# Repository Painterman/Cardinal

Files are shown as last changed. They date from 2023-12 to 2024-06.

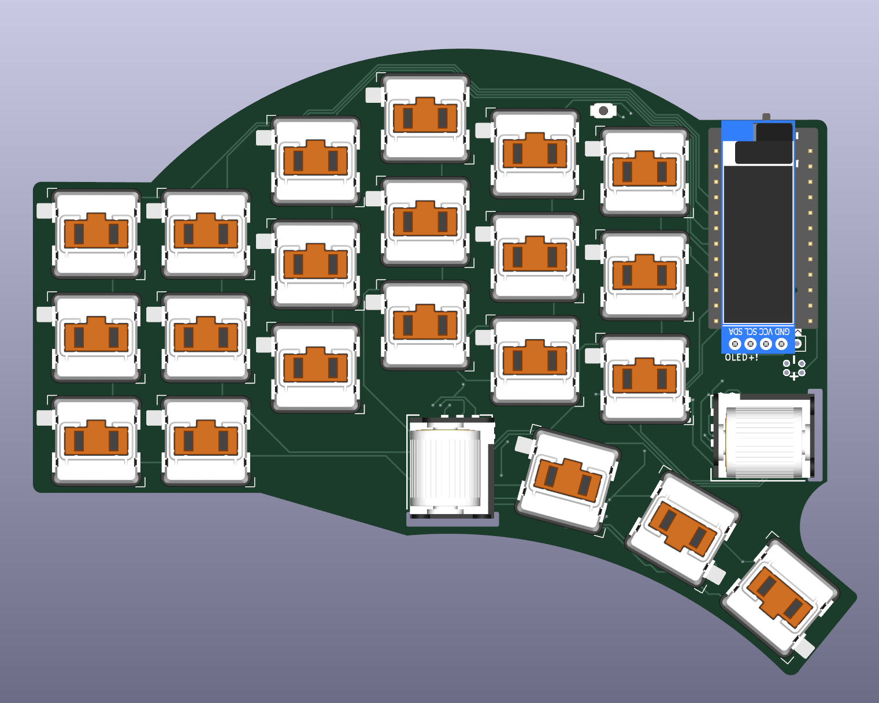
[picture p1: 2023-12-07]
Pictures/PCB-Front.png

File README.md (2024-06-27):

# Cardinal
The keyboard
 Introducing: Cardinal, a split, fully wireless, low profile with choc spacing and hotswap sockets with optional encoders, screens and 5 position switches.

 As this update this should be in a working state and mostly finished, you can find the Kicad project Gerbers ready to order, and the case files in /Case
 
# Why?

For a while now I have been using a ferris sweep on and off and wanted to go back to more keys and features. 
Looking at other keyboard projects i found about the Panasonic EVQWGD encoders and the 5 position switches like SKRHA line from alps and wanted to make a keyboard with both of these, options for displays and other features that I might like.

Fast-forward and here we are, my first keyboard design taking clues from multiple other community designs.

# Features

    -Fully wireless, designed around Nice!Nano or other controllers with the same pinout/wireless capability due to the lack of trss jack.
    -Reversible pcb.
    -2 encoders support per side, or 1 encoder and 1 5 position switch.
    -Choc spacing and hotswap sockets.
    -Oled display or Nice!View support.

 Things i might end up doing:
 
    - More versions: support for different encoders and for less keys.
    - Maybe a reduced choc spacing board.
    - Non hotswap version.
    - investigate into wireless charging

# BOM

Use this as a reference, you can find a more detailed build guide on the wiki.

| Part | Quantity | Notes| 
| :--- | :---: | :--- |
| PCB | 2 | Use your preferred pcb manufacturing service, mine came from pcbgogo (not affiliated), the size of the pcbs is 135x100, so its a bit more expensive than the sub 100x100 |
| Pro Micro footprint microcontroller | 2 | Designed with Nice!Nano Bluetooth in mind, I’m using ProMicro NRF52840 |
| Choc key switches | 42 or less | You have the option to breakaway the extra pinkie column, or even just use less thumb keys |
| Choc hotswap sockets | Same as switches | 1 per key|
| 1N4148WS SOD123 diodes  | 48 or less | 1 per key, 2 per half for encoders and 2 for 5 way switch | 
| EVQWGD001 rotary encoders | 4 or less | I’m using only 2, but the board supports up to 4(2 per side)|
| 5-way switches SKRHA family | 2 | SKRHADE010 are rated for more uses, I’m using SKRHABE010, rated for 1/5 the cycles and less expensive, here is the dataset : [SKRHA](https://www.mouser.es/datasheet/2/15/SKRH-1370966.pdf)|
| On/Off switch MSK-12C02 | 1 | Off to the right, on to the left, same on both halves |
| Lipo battery’s | 2 | You can use any you want, i like the 301230 size so it fits under the Pro Micro, but a bigger battery and a case it’s also a great option |
| Battery connectors | 2 | (optional) You can use any connector you like/have as long as the pitch its 1,5 mm, I’m using JST ZH|
| Reset switch | 2 | (optional) B3U-1000P|
| Keycaps | Same as switches | I like chosfox CFX and MBK, using CFX atm |
| 5-way switch keycap | 2 | I’m using ones that I don’t like until I design something better |
| Case | 2 | 3d printed case |

Most parts can be found on aliexpress easily, and I have seem a few offers to manufacture pcbs from vendors there, I have not tried any. My pcbs were ordered from [PCBgogo](https://www.pcbgogo.com/) and so far I’m happy with the cuality of the service and pcbs, im not affiliated with then but for now I can recommend then. Other popular option for manufacturing on the cheap is [JLCPCB](https://jlcpcb.com/) and can also recommend then, probably a better option overall due to shipping and EU import duties, prices were similar.

In terms of tenting options, the pcbs have 2 holes to support [Tenting Puck](https://splitkb.com/products/tenting-puck), i have not tested then as i don´t have any, but should fit. You could go with a case and cheap magnetic ring.

# Case

I have designed a simple case to use with the keyboard and to have a flat bottom so I can stick some kind of tenting option, I now use small kickstands for laptops.

The case design is really basic and also used it to try different cad programs so I can break free from fusion360 or other alternatives that are mostly online. Unfortunately, I will say that fusion and on shape are still the best options by a long shot for designing functional parts and Freecad/Ondsel are way too restrictive/hard to use. Even so I did end up using Ondsel to make the designs and on the /Case folder you can find stls for a 42 and 36 key configurations as well as svgs with the board outline, dxf to import into cad programs and my full Freecad project in case you wish to edit or modify then.

For printing the case, use any matterial you like and least 2 outer walls, so they end up solid, should print fine in all printers.

# Bling

Some photos, you can find more in the Pictures folder

cactus
built
vs cradio

# Inspirations and acknowledgments

First thanks to that weird friend with his weird keyboards

Heavy inspiration from Sweep https://github.com/davidphilipbarr/Sweep taking the overall shape and column stagger from it, as the reversible pcb design.

Extra pinkie column like corne https://github.com/foostan/crkbd as well as hotswap.

Inspiration from Hillside https://github.com/mmccoyd/hillside as its close to what I wanted, but also an encouragement to go further.

Encoder from Rollow  https://www.barbellboards.com/product/rollow as I fell in love with it.

5 position switches from Fulcrum https://github.com/dschil138/Fulcrum but with more keys.

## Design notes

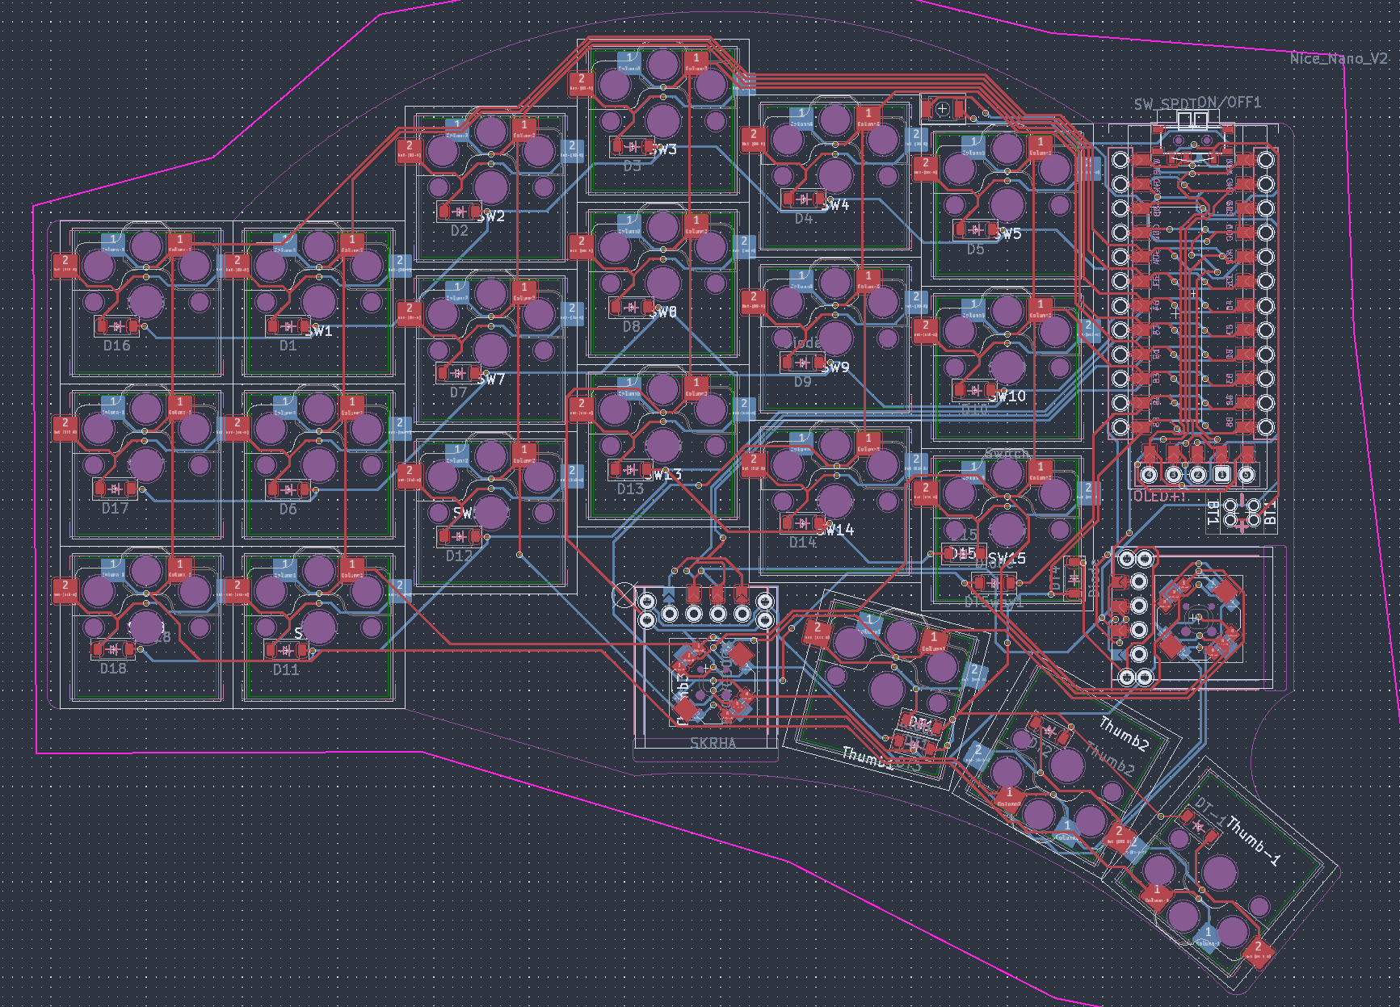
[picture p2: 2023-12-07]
Pictures/PCB-Desing.png

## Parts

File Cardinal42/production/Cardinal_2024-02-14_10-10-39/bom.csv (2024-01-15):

Designator | Footprint | Quantity | Value | LCSC Part #
_13, _12, _11, _10, _9, _8, _7, _6, _5, _4, _3, _2, | 37a111ce-96c9-42a8-b0d1-cee97aba29f6 | 13
5Way1_2, 5Way1 | SKRHA-boss_mod_doble | 2 | SKRHA
BT1_2, BT1 | JST_ZH_2PIN_1.5MM | 2 | Battery_Cell
D1, D10, D11, D12, D13, D14, D15, D16, D17, D18, D2, D3, D4, D5, D6, D7, D8, D9, DT-1, DT1, DT2, DT3, DT4, DT5way1 | Diode_SOD-123_mod | 24 | Diode
OLED+! | OLED_I2C_128x32+NiceView | 1 | OLED_I2C
ON/OFF1 | switch-MSK-12C02-smd | 1 | SW_SPDT
Reset1 | SW_SPST_B3U-1000P_mod | 1 | Reset
SW1, SW10, SW11, SW12, SW13, SW14, SW15, SW16, SW17, SW18, SW2, SW3, SW4, SW5, SW6, SW7, SW8, SW9, Thumb-1, Thumb1, Thumb2 | Hotswap_Choc_V1_1.00u_mod | 21 | Switch
Thumb3 | RollerEncoder_Panasonic_EVQWGD001_mod | 1 | EVQWGD001
Thumb4 | RollerEncoder_Panasonic_EVQWGD001_mod | 1 | EC11
U1 | ProMicro_jumpers | 1 | Nice_Nano_V2

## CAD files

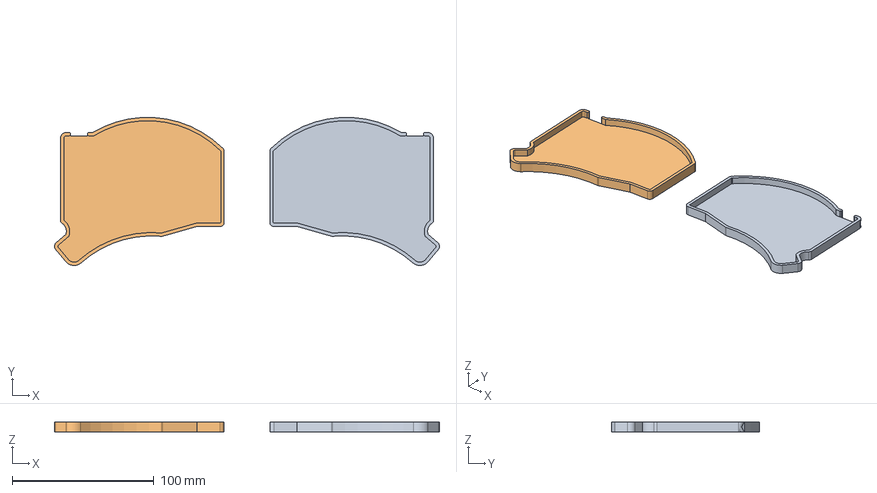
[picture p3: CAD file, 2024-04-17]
Case/Case base.FCStd
271.9 x 104.5 x 7.00 mm
Cardinal 36

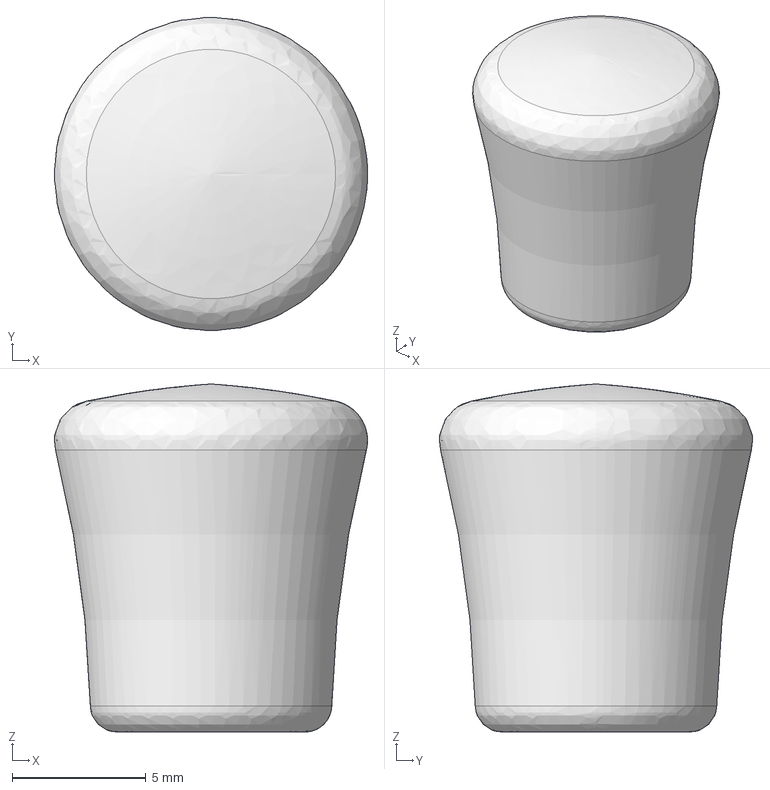
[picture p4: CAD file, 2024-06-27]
Knob/knob test.FCStd
11.7 x 11.7 x 13.0 mm

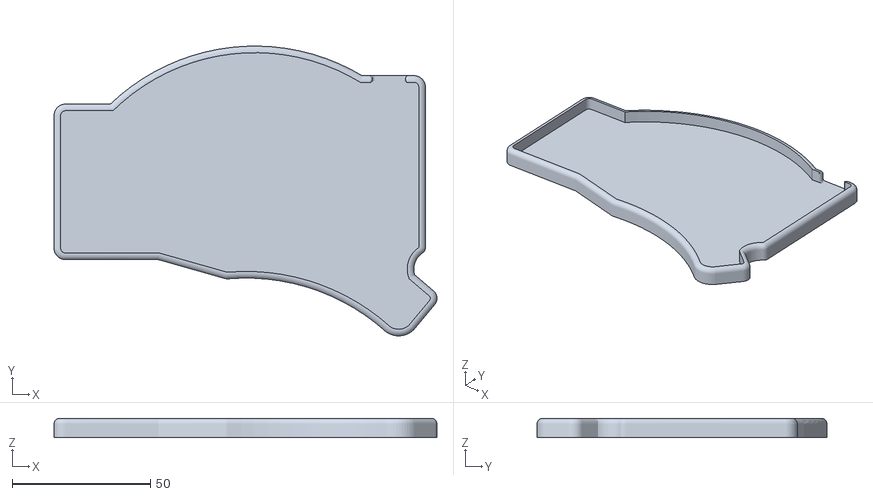
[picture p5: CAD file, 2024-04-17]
Case/Cardinal42 case Left.stl
138.4 x 104.7 x 7.03

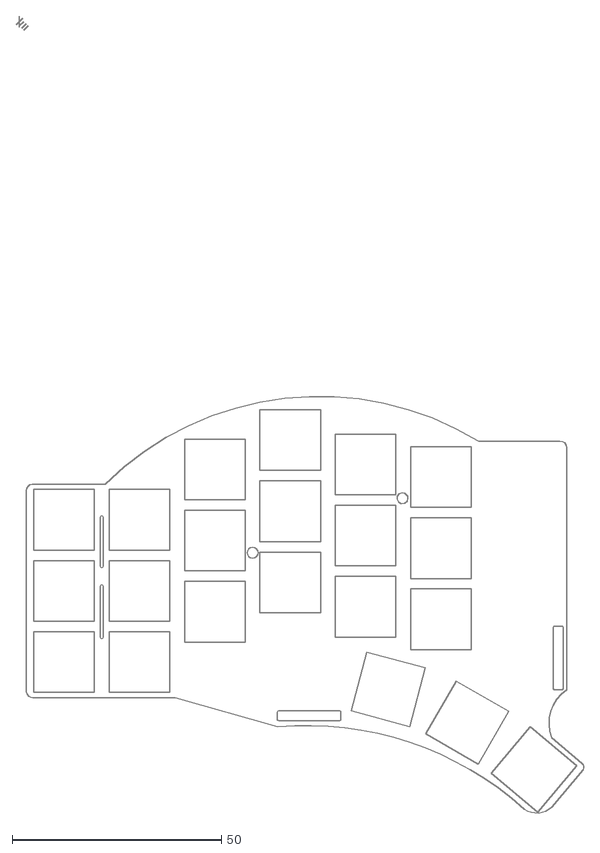
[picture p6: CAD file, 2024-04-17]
Case/Cardinal-brd.dxf
135.6 x 190.3

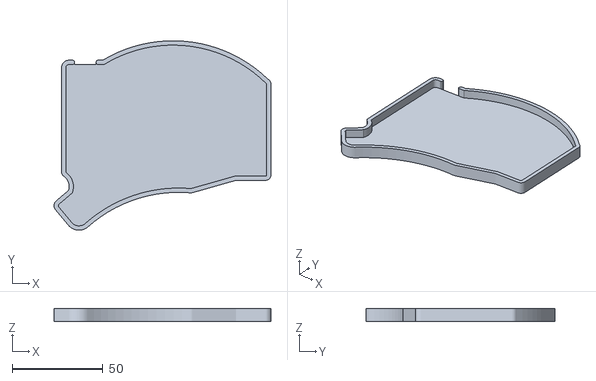
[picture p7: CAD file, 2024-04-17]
Case/Cardinal36 case Right.stl
119.9 x 104.6 x 7.00

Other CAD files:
Knob/knob.stl
Case/Cardinal42 case Right.stl
Case/Cardinal36 case Left.stl

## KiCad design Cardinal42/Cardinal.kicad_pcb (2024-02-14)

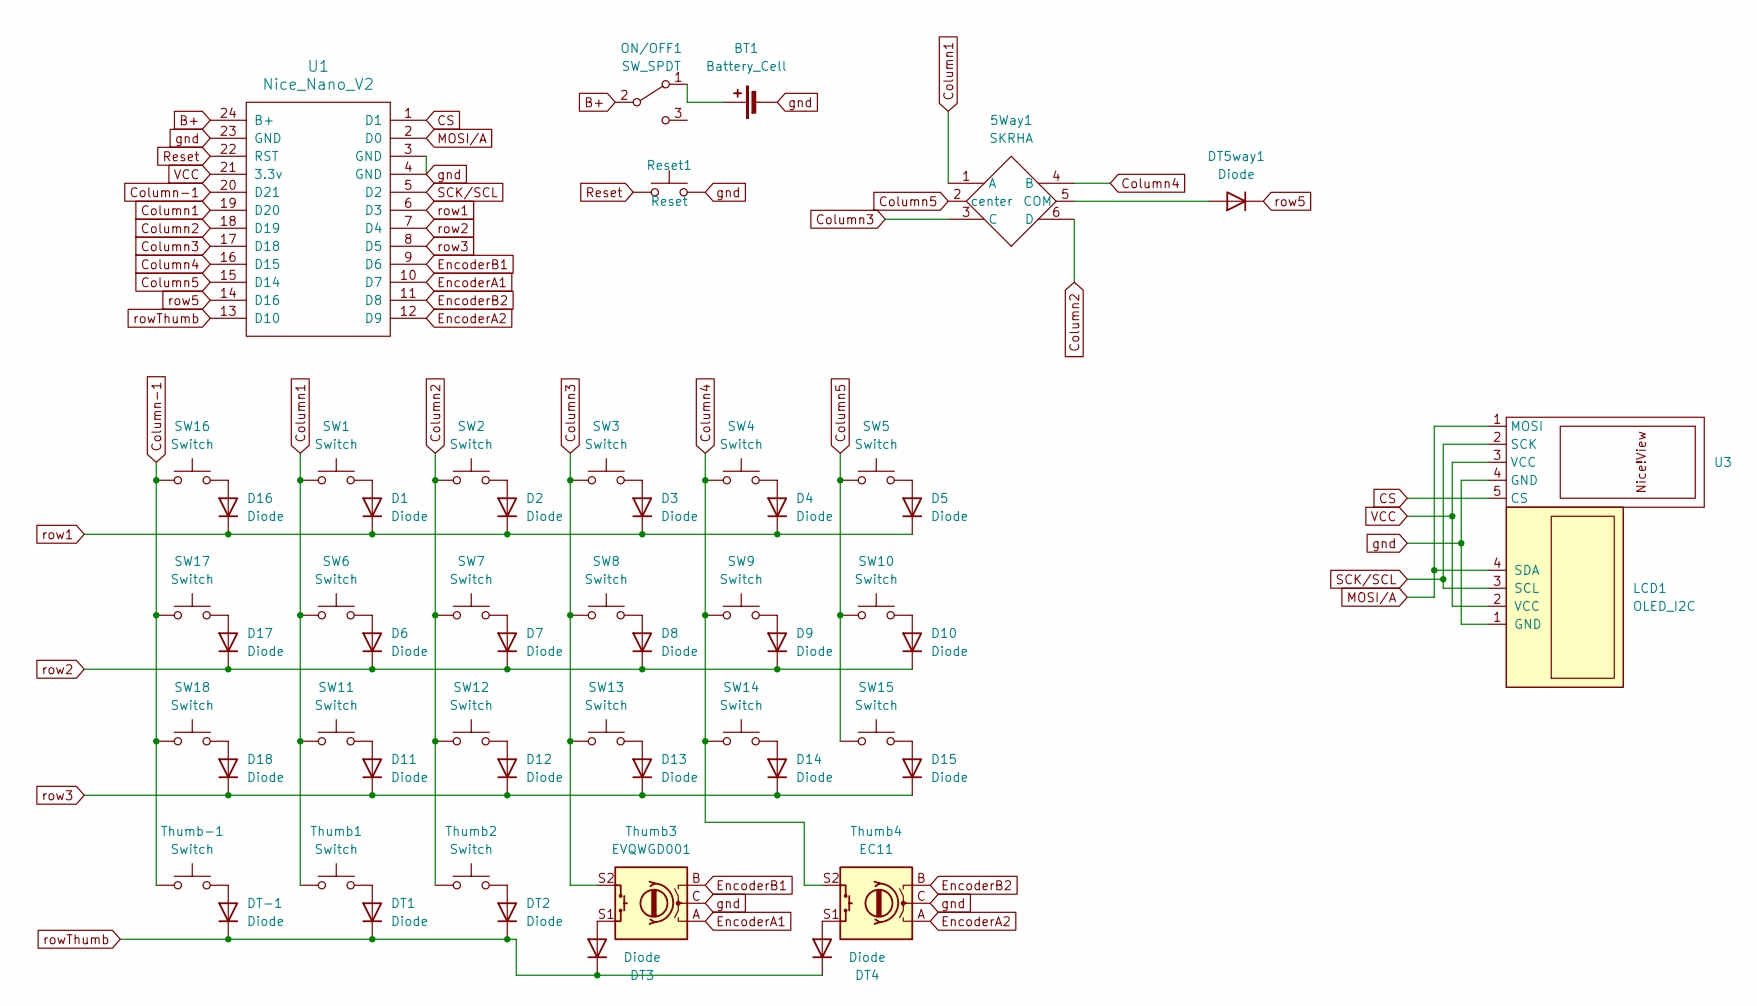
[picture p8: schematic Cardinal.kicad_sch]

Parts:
5Way1: SKRHA; SKRHA-boss_mod_doble
BT1: Battery_Cell; JST_ZH_2PIN_1.5MM
D1, D2, D3, D4, D5, D6, D7, D8, D9, D10, D11, D12, D13, D14, D15, D16, D17, D18: Diode; Diode_SOD-123_mod
DT1, DT2, DT3, DT4, DT5way1: Diode; Diode_SOD-123_mod
DT-1: Diode; Diode_SOD-123_mod
LCD1: OLED_I2C; OLED_I2C_128x32+NiceView
ON/OFF1: SW_SPDT; switch-MSK-12C02-smd
Reset1: Reset; SW_SPST_B3U-1000P_mod
SW1, SW2, SW3, SW4, SW5, SW6, SW7, SW8, SW9, SW10, SW11, SW12, SW13, SW14, SW15, SW16, SW17, SW18: Switch; Hotswap_Choc_V1_1.00u_mod
Thumb1, Thumb2: Switch; Hotswap_Choc_V1_1.00u_mod
Thumb3: EVQWGD001; RollerEncoder_Panasonic_EVQWGD001_mod
Thumb4: EC11; RollerEncoder_Panasonic_EVQWGD001_mod
Thumb-1: Switch; Hotswap_Choc_V1_1.00u_mod
U1: Nice_Nano_V2; ProMicro_jumpers
U3: (no value)

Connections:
B+: ON/OFF1.2 (B), U1.24 (B+)
CS: U1.1 (D1), U3.5 (CS)
Column1: 5Way1.1 (A), SW1.1, SW6.1, SW11.1, Thumb1.1, U1.19 (D20); also elsewhere on the board
Column2: 5Way1.6 (D), SW2.1, SW7.1, SW12.1, Thumb2.1, U1.18 (D19); also elsewhere on the board
Column3: 5Way1.3 (C), SW3.1, SW8.1, SW13.1, Thumb3.S2, U1.17 (D18); also elsewhere on the board
Column4: 5Way1.4 (B), SW4.1, SW9.1, SW14.1, Thumb4.S2, U1.16 (D15); also elsewhere on the board
Column5: 5Way1.2 (center), SW5.1, SW10.1, SW15.1, U1.15 (D14); also elsewhere on the board
Column-1: SW16.1, SW17.1, SW18.1, Thumb-1.1, U1.20 (D21)
EncoderA1: Thumb3.A, U1.10 (D7)
EncoderA2: Thumb4.A, U1.12 (D9)
EncoderB1: Thumb3.B, U1.9 (D6)
EncoderB2: Thumb4.B, U1.11 (D8)
MOSI/A: LCD1.4 (SDA), U1.2 (D0), U3.1 (MOSI)
unnamed 13: 5Way1.5 (COM), DT5way1.2 (A); also elsewhere on the board
unnamed 14: BT1.1 (+), ON/OFF1.1 (A); also elsewhere on the board
unnamed: D1.2 (A), SW1.2
unnamed: D2.2 (A), SW2.2
unnamed: D3.2 (A), SW3.2
unnamed: D4.2 (A), SW4.2
unnamed: D5.2 (A), SW5.2
unnamed: D6.2 (A), SW6.2
unnamed: D7.2 (A), SW7.2
unnamed: D8.2 (A), SW8.2
unnamed: D9.2 (A), SW9.2
unnamed: D10.2 (A), SW10.2
unnamed: D11.2 (A), SW11.2
unnamed: D12.2 (A), SW12.2
unnamed: D13.2 (A), SW13.2
unnamed: D14.2 (A), SW14.2
unnamed: D15.2 (A), SW15.2
unnamed: D16.2 (A), SW16.2
unnamed: D17.2 (A), SW17.2
unnamed: D18.2 (A), SW18.2
unnamed: DT1.2 (A), Thumb1.2
unnamed: DT2.2 (A), Thumb2.2
unnamed: DT3.2 (A), Thumb3.S1
unnamed: DT4.2 (A), Thumb4.S1
unnamed: DT-1.2 (A), Thumb-1.2
Reset: Reset1.1, U1.22 (RST)
SCK/SCL: LCD1.3 (SCL), U1.5 (D2), U3.2 (SCK)
VCC: LCD1.2 (VCC), U1.21 (3.3v), U3.3 (VCC)
gnd: BT1.2 (-), LCD1.1 (GND), Reset1.2, Thumb3.C, Thumb4.C, U1.3 (GND), U1.4 (GND), U1.23 (GND), U3.4 (GND); also elsewhere on the board
row1: D1.1 (K), D2.1 (K), D3.1 (K), D4.1 (K), D5.1 (K), D16.1 (K), U1.6 (D3)
row2: D6.1 (K), D7.1 (K), D8.1 (K), D9.1 (K), D10.1 (K), D17.1 (K), U1.7 (D4)
row3: D11.1 (K), D12.1 (K), D13.1 (K), D14.1 (K), D15.1 (K), D18.1 (K), U1.8 (D5)
row5: DT5way1.1 (K), U1.14 (D16)
rowThumb: DT1.1 (K), DT2.1 (K), DT3.1 (K), DT4.1 (K), DT-1.1 (K), U1.13 (D10)

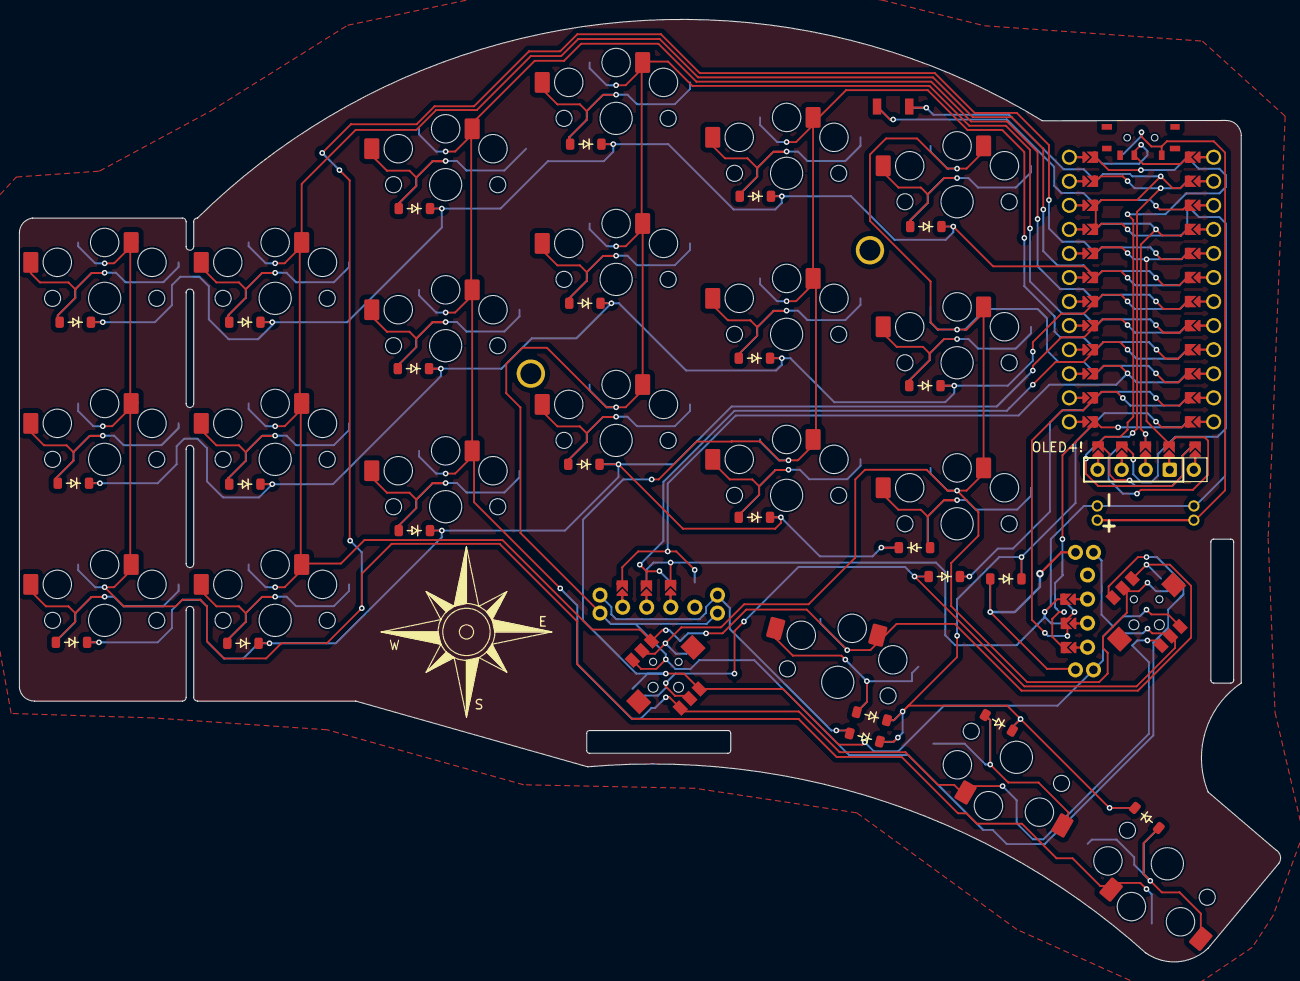
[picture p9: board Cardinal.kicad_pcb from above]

Board: 2 copper layers, 133.2 x 99.5 mm, 55 parts (1 on the bottom side), 43 nets.

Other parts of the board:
5Way1#2: SKRHA; SKRHA-boss_mod_doble
BT1#2: Battery_Cell; JST_ZH_2PIN_1.5MM
OLED+!: OLED_I2C; OLED_I2C_128x32+NiceView

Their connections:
Column1: 5Way1#2.1 (A); also elsewhere on the board
Column2: 5Way1#2.6 (D); also elsewhere on the board
Column3: 5Way1#2.3 (C); also elsewhere on the board
Column4: 5Way1#2.4 (B); also elsewhere on the board
Column5: 5Way1#2.2 (center); also elsewhere on the board
unnamed 13: 5Way1#2.5 (COM); also elsewhere on the board
unnamed 14: BT1#2.1 (+); also elsewhere on the board
gnd: BT1#2.2 (-); also elsewhere on the board

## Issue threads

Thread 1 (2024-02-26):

Build guide

alejoar, 2024-02-26:
I love this keyboard's features and key distribution.

I'm coming from a Kyria and I have been looking at the Hillside 48 for a while, but I wouldn't bite because of the missing features. The Cardinal seems to be all I wanted! Amazing job.

When can we expect the build guide to be completed?

alejoar, 2024-02-29:
Thank you @Painterman

I will hold off for now until I'm confident I can build this. The "bridging the pads" kind stuff is what prevents me from just ordering the PCB until there's proper building documentation.

Looking forward to it, thank you for the amazing work :)

alejoar, 2024-04-05:
@Painterman any chance of getting the docs any time soon? Apologies for asking, just very excited to build this keyboard!

Painterman, 2024-04-15:
Hi @alejoar

I'm sorry for the delay, the wiki/build guide should be up and finished, i dont go into a lot of detail, i assume you know how to solder and such, if you don't please look up other better tutorials online first.  Here's a direct link: https://github.com/Painterman/Cardinal/wiki/Introduction

Next is the 3d printed case, as i have been learning diferent cad programs and still getting around to it.

alejoar, 2024-04-15:
@Painterman amazing, thank you!

What PCB printing service did you use? This is my first time printing a PCB.

Also would appreciate some guidelines for the PCB request. E.g. this is what it looks like by default (except for the color) in jlcpcb.com

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

Should I change anything?

Painterman, 2024-04-15:
That is perfect, you could change the surface finish to leadfree if you wanted, up to you, for mine i did.

alejoar, 2024-05-04:
@Painterman I think I have almost all my parts!

I have a couple questions though:

1. For socketing the controller what sockets did you buy? [I bought these](https://splitkb.com/products/mill-max-low-profile-sockets?_pos=1&_sid=891e513d7&_ss=r) thinking that the male sockets that [came with the controller would fit](https://es.aliexpress.com/item/1005006271779544.html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) buy they don't :(

I guess I messed up and should have also bought the pins!

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

2. What is exact battery connector you are using? I bought a couple but I think they are too large. A link would be appreciated.

Painterman, 2024-05-04:
If you don't have the pins you could also use led legs, they should fit, test then first tho. Other common replacement is led strip connectors without the plastic insulator like these (https://es.aliexpress.com/item/32874875228.html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)

For connectors you could use any as long as fits the 1.5mm pitch, there should be plenty of space for then around, be mindfull of the polarity of the connector, positive is the lower pin. i did use jst zh (https://es.aliexpress.com/item/1005002096347570.html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) because i had then liying around, but if you have other connectors and they fit go ahead, the jst ph should also fit (2mm pitch) and they are also pretty common.

Hope it helps

alejoar, 2024-05-04:
Oh wow, do those led strip connectors fit the mill max sockets? If so I'm definitely getting a bunch of those, much cheaper than ordering pins.

For the connector, is the 2Pin/curved needle one the right one?

Thank you so much for your answer @Painterman !

Painterman, 2024-05-04:
Yes, the curved ones.

alejoar, 2024-05-25:
@Painterman quick question: I can't figure where the reset button is supposed to be soldered to. I've been looking at the pictures but can't find it. Can you point me in the right direction? Thanks!

Painterman, 2024-05-26:
Hi, its not marked, but its these 2 pads on the pcb, you can solder on either side of it, i did on the top side.

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

Have a great day!

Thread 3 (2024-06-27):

STLs for SKRHACE010 joystick cover

k3d3, 2024-06-27:
Do you have the STLs of the joysticks you're using on top of the 5-way switches? I don't know if you've put them in the repo somewhere, but I can't find them.

Painterman, 2024-06-27:
Hi, i dindt put then on the repo because im not completely sold on then tbh, at first was using ones from printables, and ended up modeling some for me, printed then on petg initially because was what i had on hand. Then i got a roll of pla and did print a new one, but the tolerances were too much and the middle click donst work.

The files for it should be on the repo about now, the master proyect and the stl, but i cant say if it will work for you, i still need to give a bit more refinement, the main issue atm is the middle click of the 5-way.

nweldev, 2024-07-05:
Here are a few others I found online if it helps:

| Name / Link | Author | Image |
|-----------|-----------|-----------|
| [Joystick Cap](https://www.printables.com/model/533196-joystick-cap) |  JJ Kim | 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 |
| [ 5 way Tactile Switch Cover](https://www.printables.com/model/17811-5-way-tactile-switch-cover) | [Jeffeb3](https://www.printables.com/@Jeffeb3) | 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
| [Nav Switch Hat for Adafruit 5 Way Navigation ](https://www.printables.com/model/162925-nav-switch-hat-for-adafruit-5-way-navigation) |[CaptainPotatoFudge](https://www.printables.com/@CaptainPotato_162114) |  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
| [ SKRHAAE010-cap ](https://www.printables.com/model/393703-skrhaae010-cap) | [Shoji Miyanishi](https://www.printables.com/@ShojiMiyanish_153905) | 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
| [Fulcrum's joystick](https://github.com/dschil138/Fulcrum/tree/main/STLs) | @dschil138 | 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
| [Joystick for tactile switch](https://www.printables.com/model/373753-joystick-for-tactile-switch) | [BanditFPVprints](https://www.printables.com/@BanditFPVprints) | 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 |
| [Analog Joystick for Arduino PlayStation And Xbox](https://www.printables.com/en/model/589033-analog-joystick-for-arduino-playstation-and-xbox) | [William Alger](https://www.printables.com/@WilliamAlger) | 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

k3d3, 2024-07-09:
After testing all of these out, I can safely say that the Fulcrum joystick (number 5) is my favourite.

Joystick 1 was a close second - it requires some modification (basically solidifying the bottom, then cutting a 2x2x2mm cube out of it), but it's pretty comfortable.

I like the concept of the d-pad (number 2), however I find it way too low - same for number 3, 4, and 6.

I tried the last one, the analog joysticks, and I found myself wanting the flattened edges that the Fulcrum joysticks have - they're really nice when using your thumb to quickly push it to one side.

---

As an aside, this got me thinking that it would be pretty neat to make a sideways-joystick mod to Cardinal, the way that Fulcrum has. I'm not a fan of a lot of the design decisions Fulcrum has made (Cardinal's thumb+pinky stagger and rollers are very important to me), but I really like the idea of the joystick on its side.

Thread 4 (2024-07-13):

SKRH setup does not allow diagonal movements

k3d3, 2024-07-13:
So I'm not sure if this is down to the wiring on the PCB, or the default ZMK config, however I don't appear to have the ability to press two directions (e.g. up and right) at the same time.

According to documents I've seen online, it should be possible on the SKRH to press up to 3 buttons (two adjacent directions and "down") at the same time, however I can't seem to get it to register more than one.

Any ideas what could be causing this? Is this something that only I'm running into?

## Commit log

2023-12-07 First commit
    Initialization of the proyect, pending of refining the PCB and generating gerbers
    [Cardinal.kicad_pcb, Cardinal.kicad_sch]
2023-12-08 Flip FIx
    Fixed a lot of footprints and traces that were "upside down", my fault when i initially made the jump-pads.
    Prep work done for column -1 being detachable.
    Testing fill plane, no gnd/vcc for it, shouldnt be necessary.
    Still planing silkscreen.
    [Cardinal.kicad_pcb]
2024-01-15 Release: V0.9
    Final desing mostly done, maybe one or two things left to refine.
    Added cutouts to reduce number of keys.
    Added logo.
    Added support for tenting puck, only 2 screws and maybe removed latter.
    Tweaked traces.
    Tested for plated holes, not convinced enough, changing in future version should be easy, but could make manufacturing problems due to the spacing from holes to pads.
    Added gerber files autogenerated with kicad, a board should be in the making.
    [Cardinal.kicad_pcb, bom.csv, designators.csv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]
2024-01-16 Minor update
    Minor update to footprints/size
    [Cardinal.kicad_pcb, bom.csv, designators.csv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]
2024-01-31 Update PCB V0.99
    After ordering pcbs and while testing then i noticed one of the pads its not conected, fixed now, at least its from one of the switches and i can add a jumper to it
    [Cardinal.kicad_pcb, bom.csv, designators.csv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]
2024-02-14 Probably V1
    Most likely this will be the release 1.0 for now on, after fixing 2 wrong traces in the desing, luckily things were an easy fix cutting a trace and adding a wire
    [Cardinal.kicad_pcb, bom.csv, designators.csv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]
2024-04-17 Big update
    Double checked most things to make sure they are fine.
    Update to readme with case information.
    Case files and extras.
    Grammar check.
    Mostly done again :D.
    [Cardinal-brd.dxf, Cardinal36 case Left.stl, Cardinal36 case Right.stl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]
2024-06-27 Update README.md
    Changed the recomended 5 way switch
2024-06-27 Knob files
    Update to the knob files to make then available, just a start on then, still need more refinement
    [knob test.FCStd, knob.stl]
